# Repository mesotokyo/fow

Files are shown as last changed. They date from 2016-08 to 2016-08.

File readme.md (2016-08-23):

MTModular Force of Waves (FoW) schematic and circuit
====================================================

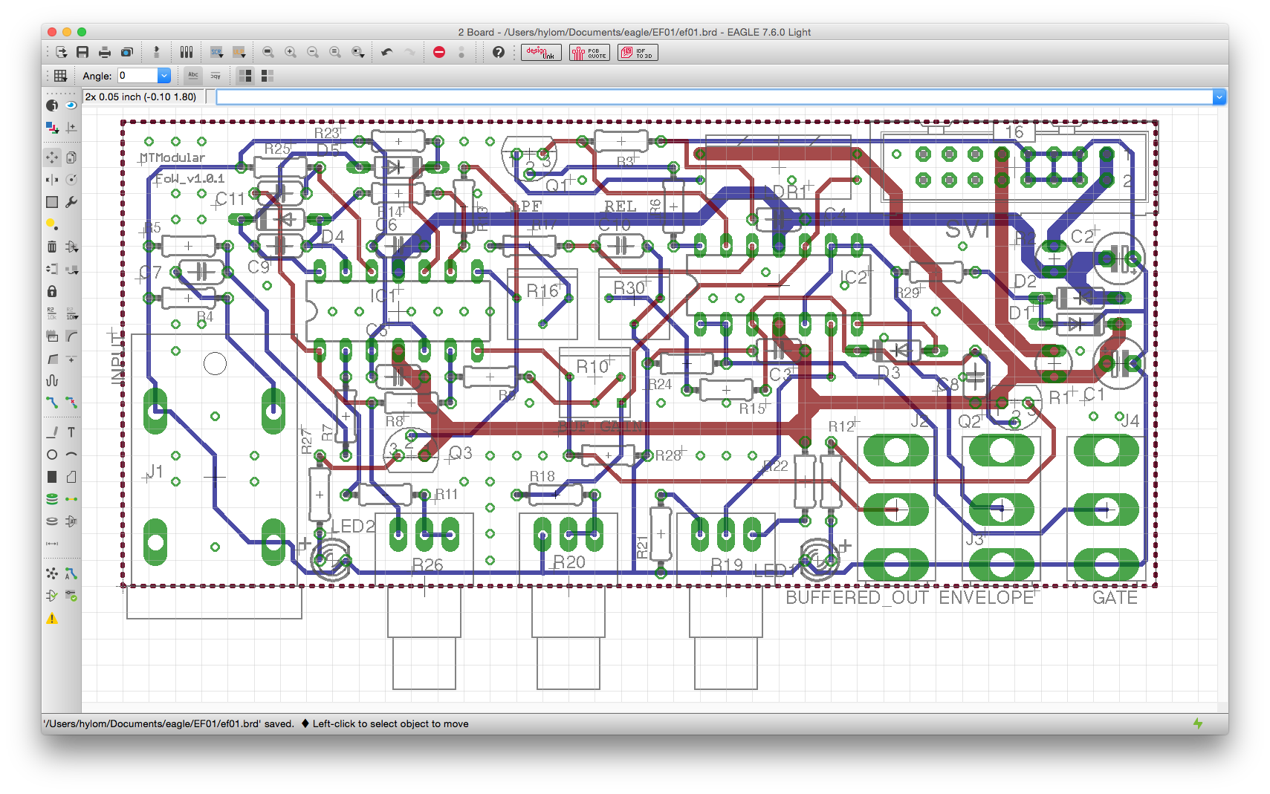
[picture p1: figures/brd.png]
board image


## about:

Force of Waves (FoW) is a "envelope follower" module for DOEPFER A-100 style system.

## features:

 * 6mm (1/4 inch) Hi-Z audio input
 * variable pre-amp gain
 * signal out: output for pre-amp buffered audio signal
 * envelope out: output for envelope signal
 * level adjuster for envelope out
 * gate out: "high" (9V) when envelope signal level is higher than threshold, otherwise "low" (0V)
 * all outputs are buffered

## author:

mesotokyo

 * twitter: @mesotokyo
 * email: meso atmark meso.tokyo
 * blog: http://b.meso.tokyo/

## license:

Creative Commons CC BY 4.0 - https://creativecommons.org/licenses/by/4.0/

## FoWについて

Force of Waves (FoW)はDOEPFER A-100などのユーロラックモジュラー向けエンベロープフォロアモジュールです。

## 特徴

 * 6mm (1/4 inch) Hi-Z オーディオ入力
 * 可変ゲインのプリアンプ
 * シグナル出力： オーディオ入力をそのままバッファリングして出力します
 * エンベロープ出力：エンベロープ信号を出力します
 * エンベロープ出力の出力レベルは調整可能です
 * ゲート出力：エンベロープ信号のレベルがしきい値（スレッショルド）を超えた場合、「High」（9V）を、そうでない場合「Low」（0V）を出力します
 * すべての出力はバッファリングされています

## 作者

mesotokyo

 * twitter: @mesotokyo
 * email: meso atmark meso.tokyo
 * blog: http://b.meso.tokyo/

## license:

Creative Commons CC BY 4.0 - https://creativecommons.org/licenses/by/4.0/

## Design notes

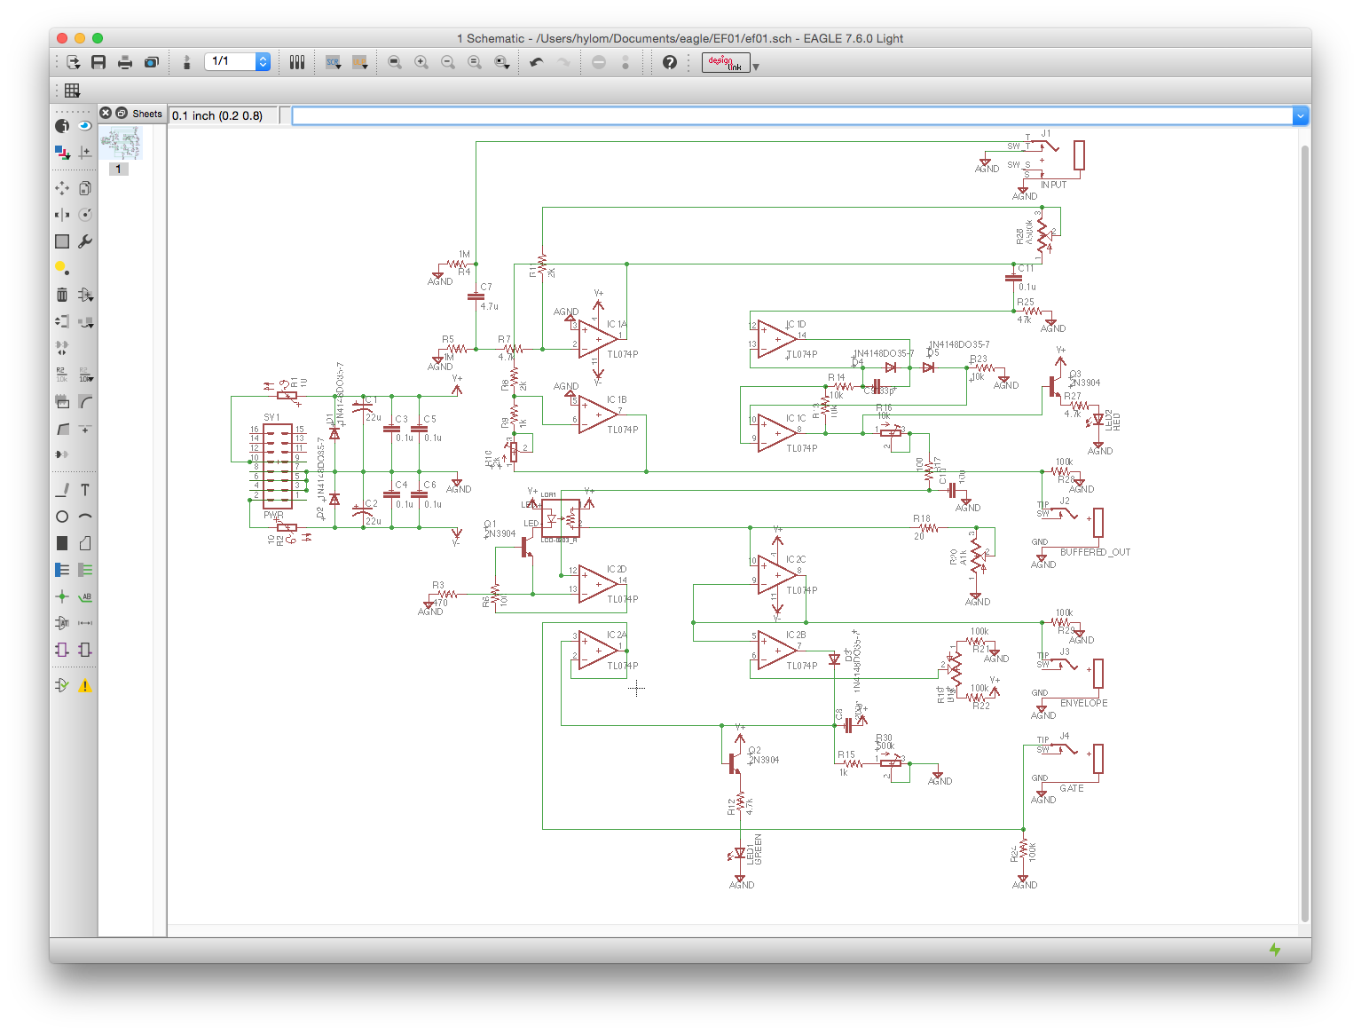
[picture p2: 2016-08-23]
figures/sch.png

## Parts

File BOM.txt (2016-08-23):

Partlist exported from /Users/hylom/Documents/eagle/EF01/ef01.sch at 2016/08/24 1:15

Part Value        Device          Package      Description                                   MF MPN OC_FARNELL OC_NEWARK
C1   22u          CPOL-USE2.5-5   E2,5-5       POLARIZED CAPACITOR, American symbol                                     
C2   22u          CPOL-USE2.5-5   E2,5-5       POLARIZED CAPACITOR, American symbol                                     
C3   0.1u         C-EU050-024X044 C050-024X044 CAPACITOR, European symbol                                               
C4   0.1u         C-EU050-024X044 C050-024X044 CAPACITOR, European symbol                                               
C5   0.1u         C-EU050-024X044 C050-024X044 CAPACITOR, European symbol                                               
C6   0.1u         C-EU050-024X044 C050-024X044 CAPACITOR, European symbol                                               
C7   4.7u         C-EU050-024X044 C050-024X044 CAPACITOR, European symbol                                               
C8   200n         C-EU050-024X044 C050-024X044 CAPACITOR, European symbol                                               
C9   33p          C-EU050-024X044 C050-024X044 CAPACITOR, European symbol                                               
C10  10u          C-EU050-024X044 C050-024X044 CAPACITOR, European symbol                                               
C11  0.1u         C-EU050-024X044 C050-024X044 CAPACITOR, European symbol                                               
D1   1N4148DO35-7 1N4148DO35-7    DO35-7       DIODE                                                                    
D2   1N4148DO35-7 1N4148DO35-7    DO35-7       DIODE                                                                    
D3   1N4148DO35-7 1N4148DO35-7    DO35-7       DIODE                                                                    
D4   1N4148DO35-7 1N4148DO35-7    DO35-7       DIODE                                                                    
D5   1N4148DO35-7 1N4148DO35-7    DO35-7       DIODE                                                                    
IC1  TL074P       TL074P          DIL14        OP AMP                                                                   
IC2  TL074P       TL074P          DIL14        OP AMP                                                                   
J1   INPUT        ACJM-MHDR       ACJM-MHDR                                                                             
J2   BUFFERED_OUT 35RAPC2AV       35RAPC2AV                                                                             
J3   ENVELOPE     35RAPC2AV       35RAPC2AV                                                                             
J4   GATE         35RAPC2AV       35RAPC2AV                                                                             
LDR1 LCD-0203_R   LCD-0203_R      LCD-0203-R   LCD-0203 - photo resistor (reversed position)                            
LED1 GREEN        LED3MM          LED3MM       LED                                                                      
LED2 RED          LED3MM          LED3MM       LED                                                                      
Q1   2N3904       2N3904          TO92         NPN Transistor                                                           
Q2   2N3904       2N3904          TO92         NPN Transistor                                                           
Q3   2N3904       2N3904          TO92         NPN Transistor                                                           
R1   10           PTC679          P679         PHILIPS PTC                                          unknown    unknown  
R2   10           PTC679          P679         PHILIPS PTC                                          unknown    unknown  
R3   470          R-US_0204/7     0204/7       RESISTOR, American symbol                                                
R4   1M           R-US_0204/7     0204/7       RESISTOR, American symbol                                                
R5   1M           R-US_0204/7     0204/7       RESISTOR, American symbol                                                
R6   100          R-US_0204/7     0204/7       RESISTOR, American symbol                                                
R7   4.7k         R-US_0204/7     0204/7       RESISTOR, American symbol                                                
R8   2k           R-US_0204/7     0204/7       RESISTOR, American symbol                                                
R9   1k           R-US_0204/7     0204/7       RESISTOR, American symbol                                                
R10  2k           GFP063P         GF063P       TOCOS GF063P - SINGLE TURN CERMET TRIMMER                                
R11  2k           R-US_0204/7     0204/7       RESISTOR, American symbol                                                
R12  4.7k         R-US_0204/7     0204/7       RESISTOR, American symbol                                                
R13  10k          R-US_0204/7     0204/7       RESISTOR, American symbol                                                
R14  10k          R-US_0204/7     0204/7       RESISTOR, American symbol                                                
R15  1k           R-US_0204/7     0204/7       RESISTOR, American symbol                                                
R16  10k          GFP063P         GF063P       TOCOS GF063P - SINGLE TURN CERMET TRIMMER                                
R17  100          R-US_0204/7     0204/7       RESISTOR, American symbol                                                
R18  20           R-US_0204/7     0204/7       RESISTOR, American symbol                                                
R19  B1k          RK097111        RK097111     ALPS RK097111 - 9mm horizontal rotary volume                             
R20  A1k          RK097111        RK097111     ALPS RK097111 - 9mm horizontal rotary volume                             
R21  100k         R-US_0204/7     0204/7       RESISTOR, American symbol                                                
R22  100k         R-US_0204/7     0204/7       RESISTOR, American symbol                                                
R23  10k          R-US_0204/7     0204/7       RESISTOR, American symbol                                                
R24  100k         R-US_0204/7     0204/7       RESISTOR, American symbol                                                
R25  47k          R-US_0204/7     0204/7       RESISTOR, American symbol                                                
R26  A500k        RK097111        RK097111     ALPS RK097111 - 9mm horizontal rotary volume                             
R27  4.7k         R-US_0204/7     0204/7       RESISTOR, American symbol                                                
R28  100k         R-US_0204/7     0204/7       RESISTOR, American symbol                                                
R29  100k         R-US_0204/7     0204/7       RESISTOR, American symbol                                                
R30  500k         GFP063P         GF063P       TOCOS GF063P - SINGLE TURN CERMET TRIMMER                                
SV1  PWR          ML16            ML16         HARTING                                              unknown    unknown

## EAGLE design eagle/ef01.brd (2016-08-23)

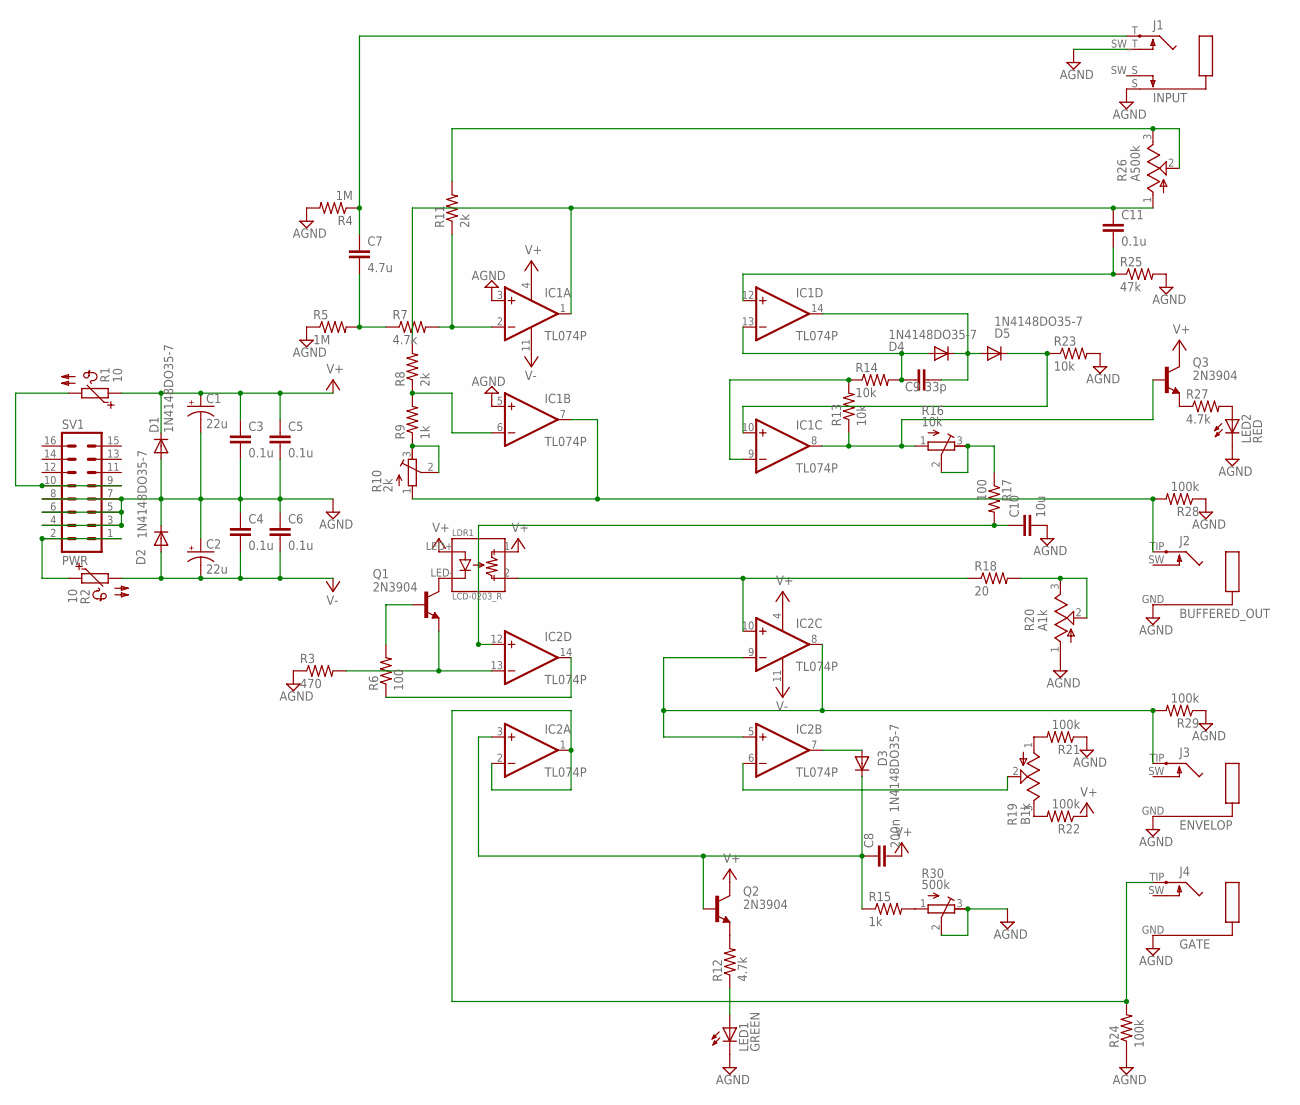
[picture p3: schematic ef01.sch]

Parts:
C1, C2: 22u; E2,5-5
C3, C4, C5, C6, C11: 0.1u; C050-024X044
C7: 4.7u; C050-024X044
C8: 200n; C050-024X044
C9: 33p; C050-024X044
C10: 10u; C050-024X044
D1, D2, D3, D4, D5: 1N4148DO35-7; DO35-7
IC1, IC2: TL074P; DIL14
J1: INPUT; ACJM-MHDR
J2: BUFFERED_OUT; 35RAPC2AV
J3: ENVELOP; 35RAPC2AV
J4: GATE; 35RAPC2AV
LDR1: LCD-0203_R; LCD-0203-R
LED1: GREEN; LED3MM
LED2: RED; LED3MM
Q1, Q2, Q3: 2N3904; TO92
R1, R2: 10; P679
R3: 470; 0204/7
R4, R5: 1M; 0204/7
R6, R17: 100; 0204/7
R7, R12, R27: 4.7k; 0204/7
R8, R11: 2k; 0204/7
R9, R15: 1k; 0204/7
R10: 2k; GF063P
R13, R14, R23: 10k; 0204/7
R16: 10k; GF063P
R18: 20; 0204/7
R19: B1k; RK097111
R20: A1k; RK097111
R21, R22, R24, R28, R29: 100k; 0204/7
R25: 47k; 0204/7
R26: A500k; RK097111
R30: 500k; GF063P
SV1: PWR; ML16

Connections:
AGND: C1.-, C2.+, C3.2, C4.1, C5.2, C6.1, C10.2, D1.A, D2.C, IC1.3 (+IN), IC1.5 (+IN), J1.S (GND), J1.SW_T (T_SW), J2.GND, J3.GND, J4.GND, LED1.K (C), LED2.K (C), R3.1, R4.2, R5.1, R20.1, R21.1, R23.2, R24.1, R25.2, R28.1, R29.1, R30.2, R30.3, SV1.3, SV1.4, SV1.5, SV1.6, SV1.7, SV1.8
LDR1: C10.1, IC2.12 (+IN), R17.2
unnamed: C7.1, J1.T (TIP), R4.1
unnamed: C7.2, R5.2, R7.1
unnamed: Q1.2 (B), R6.2
unnamed: IC1.6 (-IN), R8.1, R9.2
unnamed: R9.1, R10.2, R10.3
unnamed: C11.1, IC1.1 (OUT), R8.2, R26.1
unnamed: IC1.7 (OUT), J2.TIP, R10.1, R28.2
unnamed: IC1.2 (-IN), R7.2, R11.1
unnamed: C11.2, IC1.12 (+IN), R25.1
unnamed: C9.1, D4.A, IC1.13 (-IN), R14.2
unnamed: IC1.8 (OUT), Q3.2 (B), R13.1, R16.1
unnamed: R16.2, R16.3, R17.1
unnamed: LDR1.LED- (D-), Q1.1 (C)
unnamed: IC1.9 (-IN), R13.2, R14.1
unnamed: C9.2, D4.C, D5.A, IC1.14 (OUT)
unnamed: D5.C, IC1.10 (+IN), R23.1
unnamed: Q3.3 (E), R27.1
unnamed: LED2.A, R27.2
unnamed: IC2.13 (-IN), Q1.3 (E), R3.2
unnamed: IC2.14 (OUT), R6.1
unnamed: R18.2, R20.2, R20.3
unnamed: IC2.10 (+IN), LDR1.2, R18.1
unnamed: R15.2, R30.1
unnamed: IC2.5 (+IN), IC2.8 (OUT), IC2.9 (-IN), J3.TIP, R29.2
unnamed: R19.1, R21.2
unnamed: R19.3, R22.2
unnamed: IC2.6 (-IN), R19.2
unnamed: D3.A, IC2.7 (OUT)
unnamed: Q2.3 (E), R12.2
unnamed: LED1.A, R12.1
unnamed: C8.1, D3.C, IC2.3 (+IN), Q2.2 (B), R15.1
unnamed: IC2.1 (OUT), IC2.2 (-IN), J4.TIP, R24.2
unnamed: R2.1, SV1.1, SV1.2
unnamed: R1.2, SV1.9, SV1.10
unnamed: R11.2, R26.2, R26.3
V+: C1.+, C3.1, C5.1, C8.2, D1.C, IC1.4 (V+), IC2.4 (V+), LDR1.1, LDR1.LED+ (D+), Q2.1 (C), Q3.1 (C), R1.1, R22.1
V-: C2.-, C4.2, C6.2, D2.A, IC1.11 (V-), IC2.11 (V-), R2.2

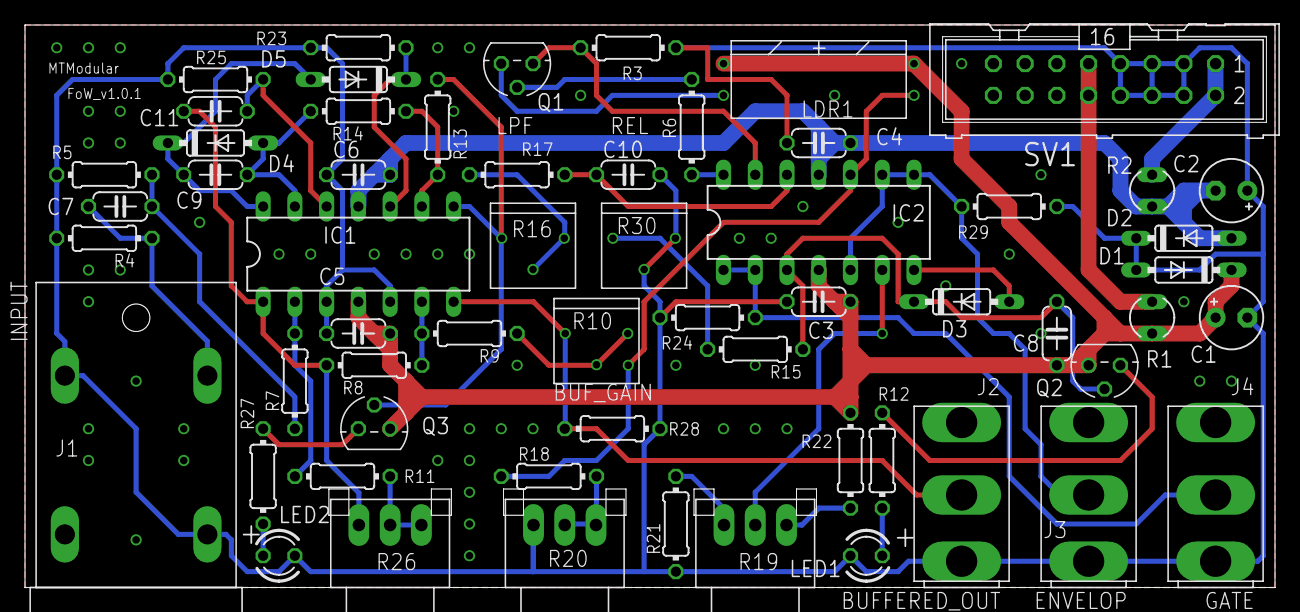
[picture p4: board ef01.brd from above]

Board: 2 copper layers, 100.0 x 45.0 mm, 59 parts (0 on the bottom side), 39 nets.

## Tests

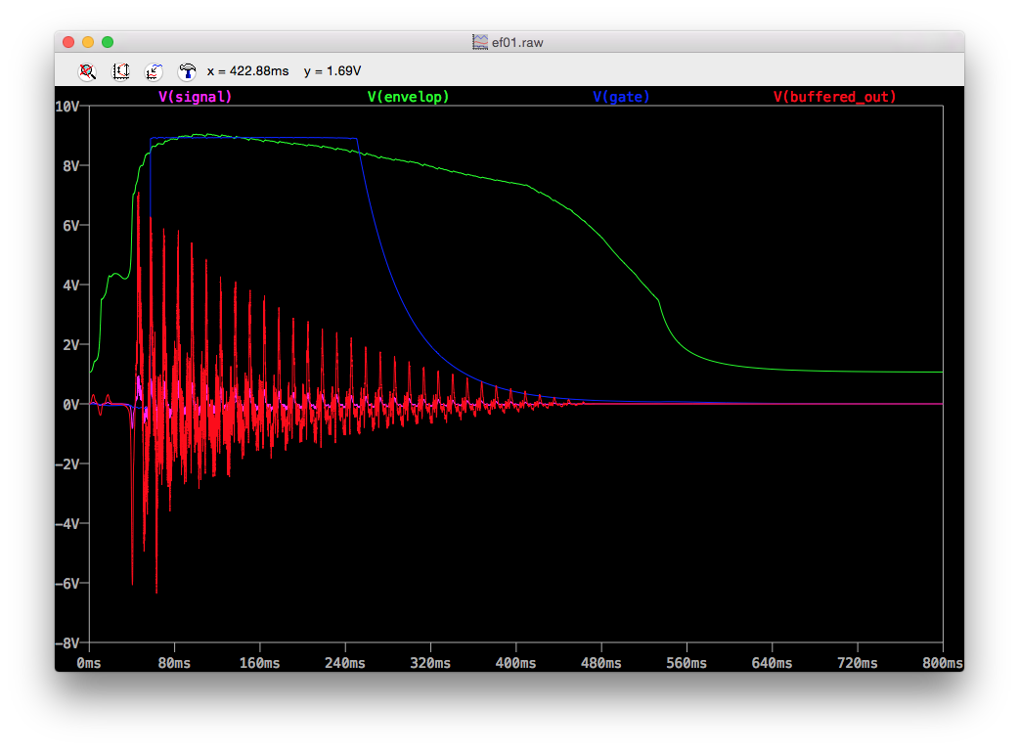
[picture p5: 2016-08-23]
figures/sample_result.png
